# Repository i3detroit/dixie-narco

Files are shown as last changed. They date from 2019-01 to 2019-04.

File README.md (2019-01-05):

# dixie-narco
Replacement controller for a Dixie-Narco drink vending machine

Initial reverse-engineering and machine details located in the history of the [equipment page](https://www.i3detroit.org/wiki/Dixie_Narco_Soda_Machine), which will be a living document for the current status of the machine.

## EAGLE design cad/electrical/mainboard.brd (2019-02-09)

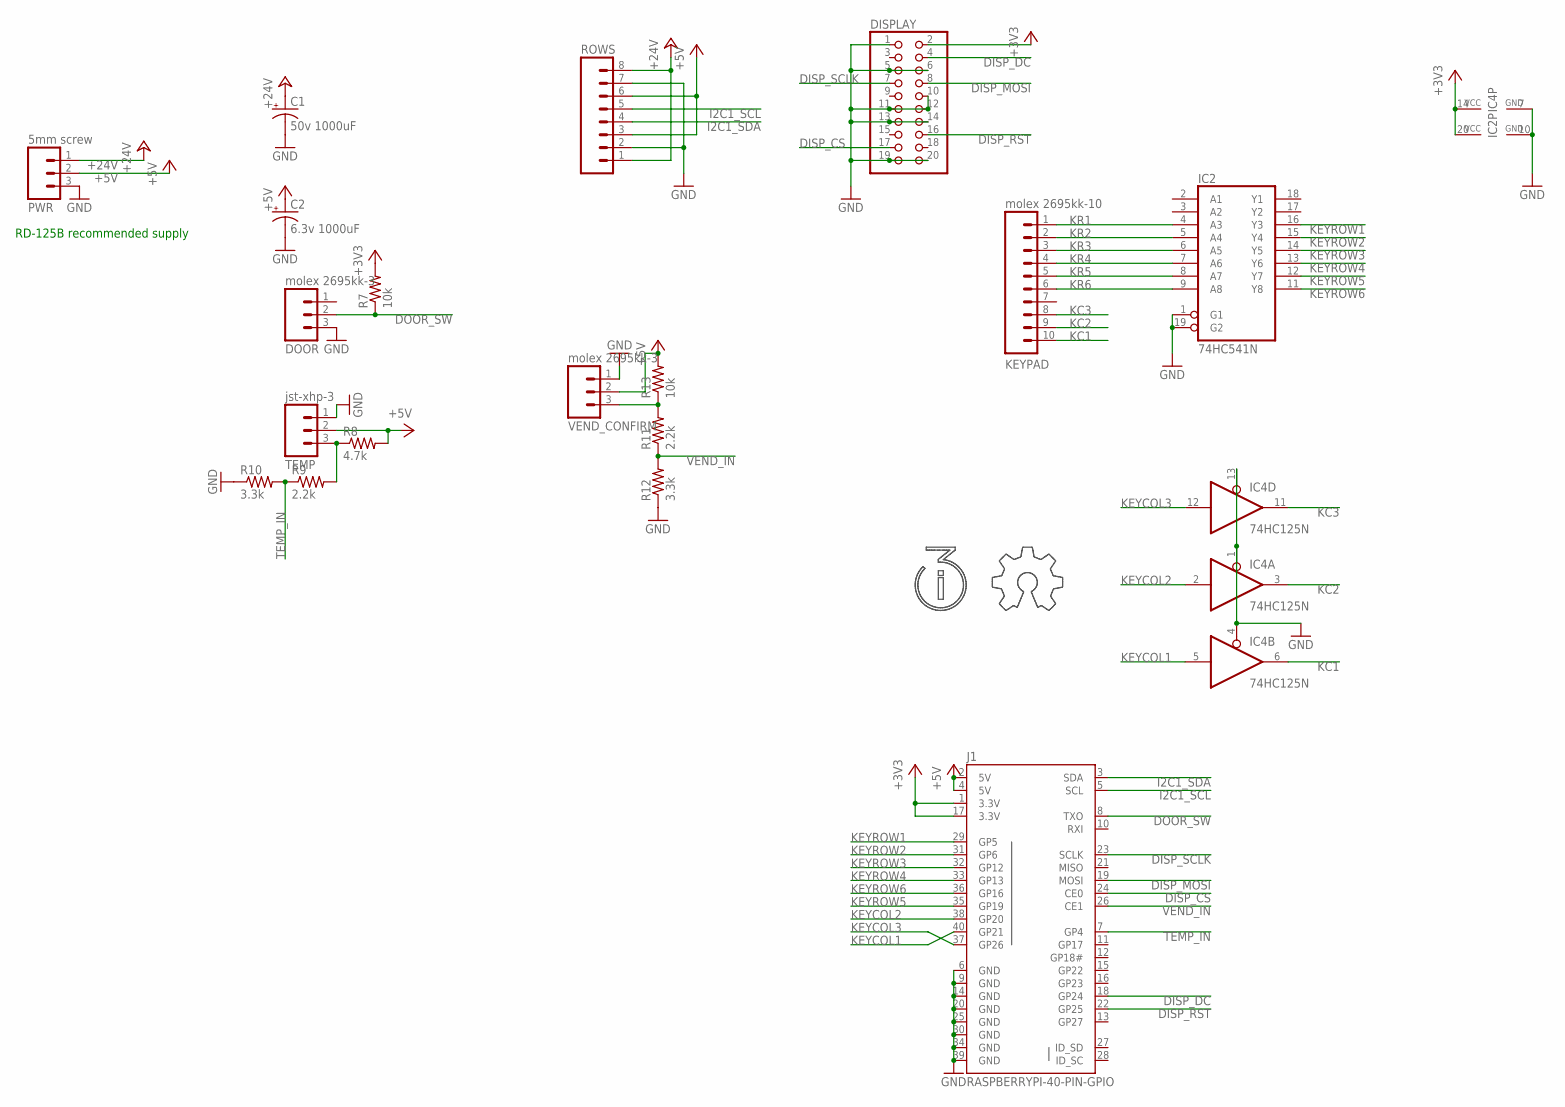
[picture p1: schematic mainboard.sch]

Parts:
C1: 50v 1000uF; CPOL-RADIAL-1000UF-25V
C2: 6.3v 1000uF; CPOL-RADIAL-1000UF-25V
DISPLAY: PINHD-2X10; 2X10
DOOR: molex 2695kk-3; MOLEX-1X3
IC2: 74HC541N; DIL20
IC4: 74HC125N; DIL14
J1: RASPBERRYPI-40-PIN-GPIO; 2X20-SHROUDED
KEYPAD: molex 2695kk-10; 1X10_LOCK
PWR: 5mm screw; SCREWTERMINAL-5MM-3
R7, R13: 10k; 1206
R8: 4.7k; 1206
R9, R11: 2.2k; 1206
R10, R12: 3.3k; 1206
ROWS: M08FEMALE_LOCK; 1X08_FEMALE_LOCK
TEMP: jst-xhp-3; 1X03
U$1: I3LOGO
U$2: OSHWLOGO
VEND_CONFIRM: molex 2695kk-3; MOLEX-1X3

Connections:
+3V3: DISPLAY.2, IC2.20 (VCC), IC4.14 (VCC), J1.1 (3.3V), J1.17 (3.3V), R7.2
+5V: C2.+, J1.2 (5V), J1.4 (5V), PWR.2, R8.2, R13.2, ROWS.3, ROWS.6, TEMP.2, VEND_CONFIRM.2
+24V: C1.+, PWR.1, ROWS.1, ROWS.8
DISP_CS: DISPLAY.17, J1.24 (CE0)
DISP_DC: DISPLAY.4, J1.18 (GP24)
DISP_MOSI: DISPLAY.8, J1.19 (MOSI)
DISP_RST: DISPLAY.16, J1.22 (GP25)
DISP_SCLK: DISPLAY.7, J1.23 (SCLK)
DOOR_SW: DOOR.2, J1.8 (TXO), R7.1
GND: C1.-, C2.-, DISPLAY.1, DISPLAY.5, DISPLAY.6, DISPLAY.10, DISPLAY.11, DISPLAY.12, DISPLAY.13, DISPLAY.14, DISPLAY.19, DISPLAY.20, DOOR.3, IC2.1 (G1), IC2.10 (GND), IC2.19 (G2), IC4.1 (OE), IC4.4 (OE), IC4.7 (GND), IC4.13 (OE), J1.6 (GND), J1.9 (GND), J1.14 (GND), J1.20 (GND), J1.25 (GND), J1.30 (GND), J1.34 (GND), J1.39 (GND), PWR.3, R10.1, R12.1, ROWS.2, ROWS.7, TEMP.1, VEND_CONFIRM.1
I2C1_SCL: J1.5 (SCL), ROWS.5
I2C1_SDA: J1.3 (SDA), ROWS.4
KC1: IC4.6 (O), KEYPAD.10
KC2: IC4.3 (O), KEYPAD.9
KC3: IC4.11 (O), KEYPAD.8
KEYCOL1: IC4.5 (I), J1.40 (GP21)
KEYCOL2: IC4.2 (I), J1.38 (GP20)
KEYCOL3: IC4.12 (I), J1.37 (GP26)
KEYROW1: IC2.16 (Y3), J1.29 (GP5)
KEYROW2: IC2.15 (Y4), J1.31 (GP6)
KEYROW3: IC2.14 (Y5), J1.32 (GP12)
KEYROW4: IC2.13 (Y6), J1.33 (GP13)
KEYROW5: IC2.12 (Y7), J1.35 (GP19)
KEYROW6: IC2.11 (Y8), J1.36 (GP16)
KR1: IC2.4 (A3), KEYPAD.1
KR2: IC2.5 (A4), KEYPAD.2
KR3: IC2.6 (A5), KEYPAD.3
KR4: IC2.7 (A6), KEYPAD.4
KR5: IC2.8 (A7), KEYPAD.5
KR6: IC2.9 (A8), KEYPAD.6
unnamed: R8.1, R9.2, TEMP.3
unnamed: R11.2, R13.1, VEND_CONFIRM.3
TEMP_IN: J1.7 (GP4), R9.1, R10.2
VEND_IN: J1.26 (CE1), R11.1, R12.2

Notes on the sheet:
RD-125B recommended supply

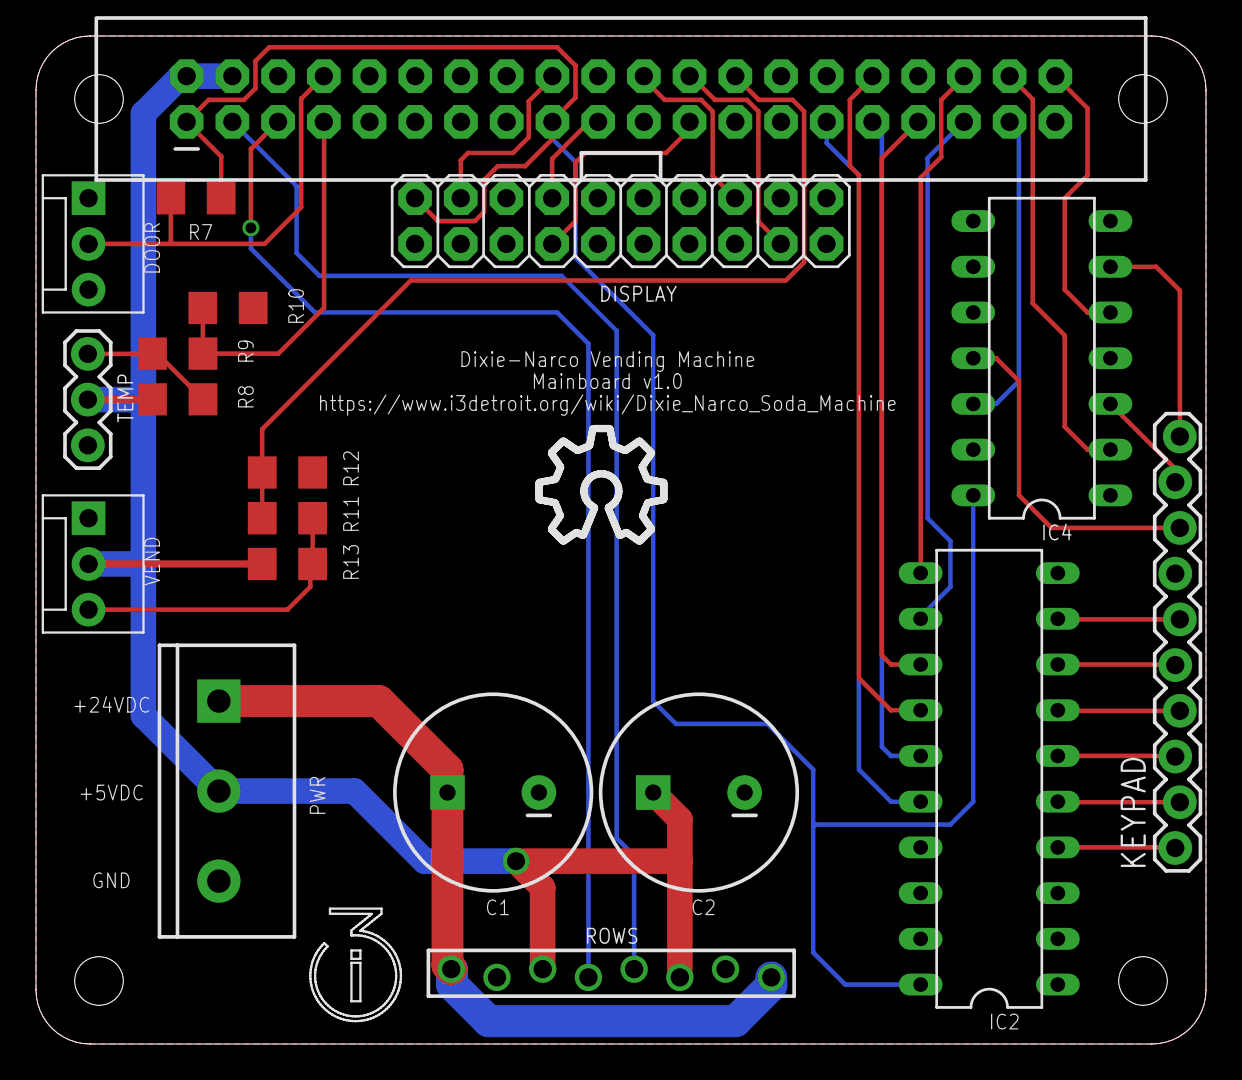
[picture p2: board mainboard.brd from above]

Board: 2 copper layers, 65.0 x 56.0 mm, 21 parts (0 on the bottom side), 34 nets.

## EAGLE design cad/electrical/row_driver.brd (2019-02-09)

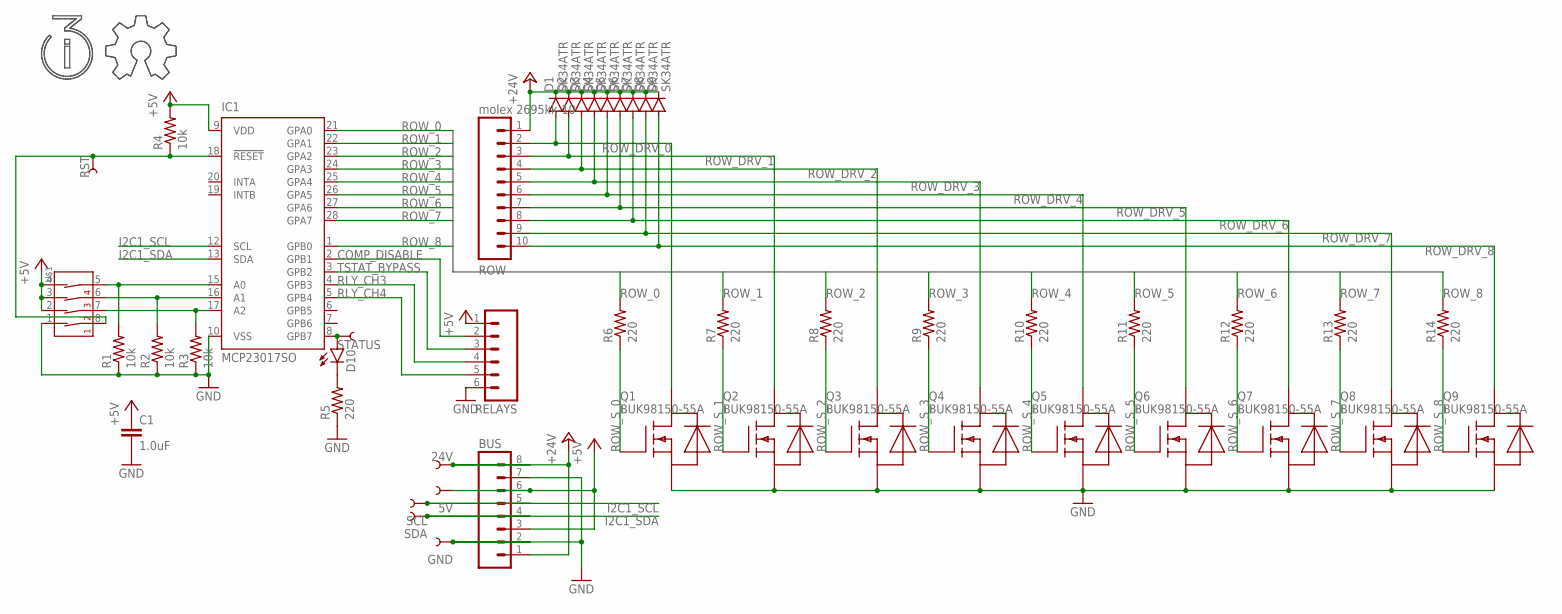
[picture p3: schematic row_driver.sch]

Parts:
5V, 24V: TEST-POINTTP_15TH_THRU; TP_15TH
BUS: M08FEMALE_LOCK; 1X08_FEMALE_LOCK
C1: 1.0uF; 0603-CAP
D1, D2, D3, D4, D5, D6, D7, D8, D9: SK34ATR; SMA-DIODE
D10: LED1206; LED-1206
GND: TEST-POINTTP_15TH_THRU; TP_15TH
IC1: MCP23017SO; SO28W
Q1, Q2, Q3, Q4, Q5, Q6, Q7, Q8, Q9: BUK98150-55A; SOT223
R1, R2, R3, R4: 10k; 0805
R5, R6, R7, R8, R9, R10, R11, R12, R13, R14: 220; 0805
RELAYS: M06LOCK; 1X06_LOCK
ROW: molex 2695kk-10; 1X10_LOCK
RST: TEST-POINTTP_15TH_THRU; TP_15TH
SCL: TEST-POINTTP_15TH_THRU; TP_15TH
SDA: TEST-POINTTP_15TH_THRU; TP_15TH
STATUS: TEST-POINTTP_15TH_THRU; TP_15TH
U$1: 4-POS-DIP; 4-POS-DIP-SMD
U$2: I3LOGO
U$4: OSHWLOGO

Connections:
+5V: 5V.P$1, BUS.3, BUS.6, C1.1, IC1.9 (VDD), R4.2, RELAYS.1, U$1.2 (2A), U$1.3 (3A), U$1.4 (4A)
+24V: 24V.P$1, BUS.1, BUS.8, D1.C, D2.C, D3.C, D4.C, D5.C, D6.C, D7.C, D8.C, D9.C, ROW.1
A0: IC1.15 (A0), R1.2, U$1.5 (4B)
A1: IC1.16 (A1), R2.2, U$1.6 (3B)
A2: IC1.17 (A2), R3.2, U$1.7 (2B)
COMP_DISABLE: IC1.2 (GPB1), RELAYS.2
GND: BUS.2, BUS.7, C1.2, GND.P$1, IC1.10 (VSS), Q1.3 (S), Q2.3 (S), Q3.3 (S), Q4.3 (S), Q5.3 (S), Q6.3 (S), Q7.3 (S), Q8.3 (S), Q9.3 (S), R1.1, R2.1, R3.1, R5.1, RELAYS.6, U$1.1 (1A)
I2C1_SCL: BUS.5, IC1.12 (SCL), SCL.P$1
I2C1_SDA: BUS.4, IC1.13 (SDA), SDA.P$1
unnamed: D10.C, R5.2
RLY_CH3: IC1.4 (GPB3), RELAYS.4
RLY_CH4: IC1.5 (GPB4), RELAYS.5
ROW_0: IC1.21 (GPA0), R6.2
ROW_1: IC1.22 (GPA1), R7.2
ROW_2: IC1.23 (GPA2), R8.2
ROW_3: IC1.24 (GPA3), R9.2
ROW_4: IC1.25 (GPA4), R10.2
ROW_5: IC1.26 (GPA5), R11.2
ROW_6: IC1.27 (GPA6), R12.2
ROW_7: IC1.28 (GPA7), R13.2
ROW_8: IC1.1 (GPB0), R14.2
ROW_DRV_0: D1.A, Q1.2 (D), Q1.4 (D), ROW.2
ROW_DRV_1: D2.A, Q2.2 (D), Q2.4 (D), ROW.3
ROW_DRV_2: D3.A, Q3.2 (D), Q3.4 (D), ROW.4
ROW_DRV_3: D4.A, Q4.2 (D), Q4.4 (D), ROW.5
ROW_DRV_4: D5.A, Q5.2 (D), Q5.4 (D), ROW.6
ROW_DRV_5: D6.A, Q6.2 (D), Q6.4 (D), ROW.7
ROW_DRV_6: D7.A, Q7.2 (D), Q7.4 (D), ROW.8
ROW_DRV_7: D8.A, Q8.2 (D), Q8.4 (D), ROW.9
ROW_DRV_8: D9.A, Q9.2 (D), Q9.4 (D), ROW.10
ROW_S_0: Q1.1 (G), R6.1
ROW_S_1: Q2.1 (G), R7.1
ROW_S_2: Q3.1 (G), R8.1
ROW_S_3: Q4.1 (G), R9.1
ROW_S_4: Q5.1 (G), R10.1
ROW_S_5: Q6.1 (G), R11.1
ROW_S_6: Q7.1 (G), R12.1
ROW_S_7: Q8.1 (G), R13.1
ROW_S_8: Q9.1 (G), R14.1
RST: IC1.18 (!RESET), R4.1, RST.P$1, U$1.8 (1B)
STATUS: D10.A, IC1.8 (GPB7), STATUS.P$1
TSTAT_BYPASS: IC1.3 (GPB2), RELAYS.3

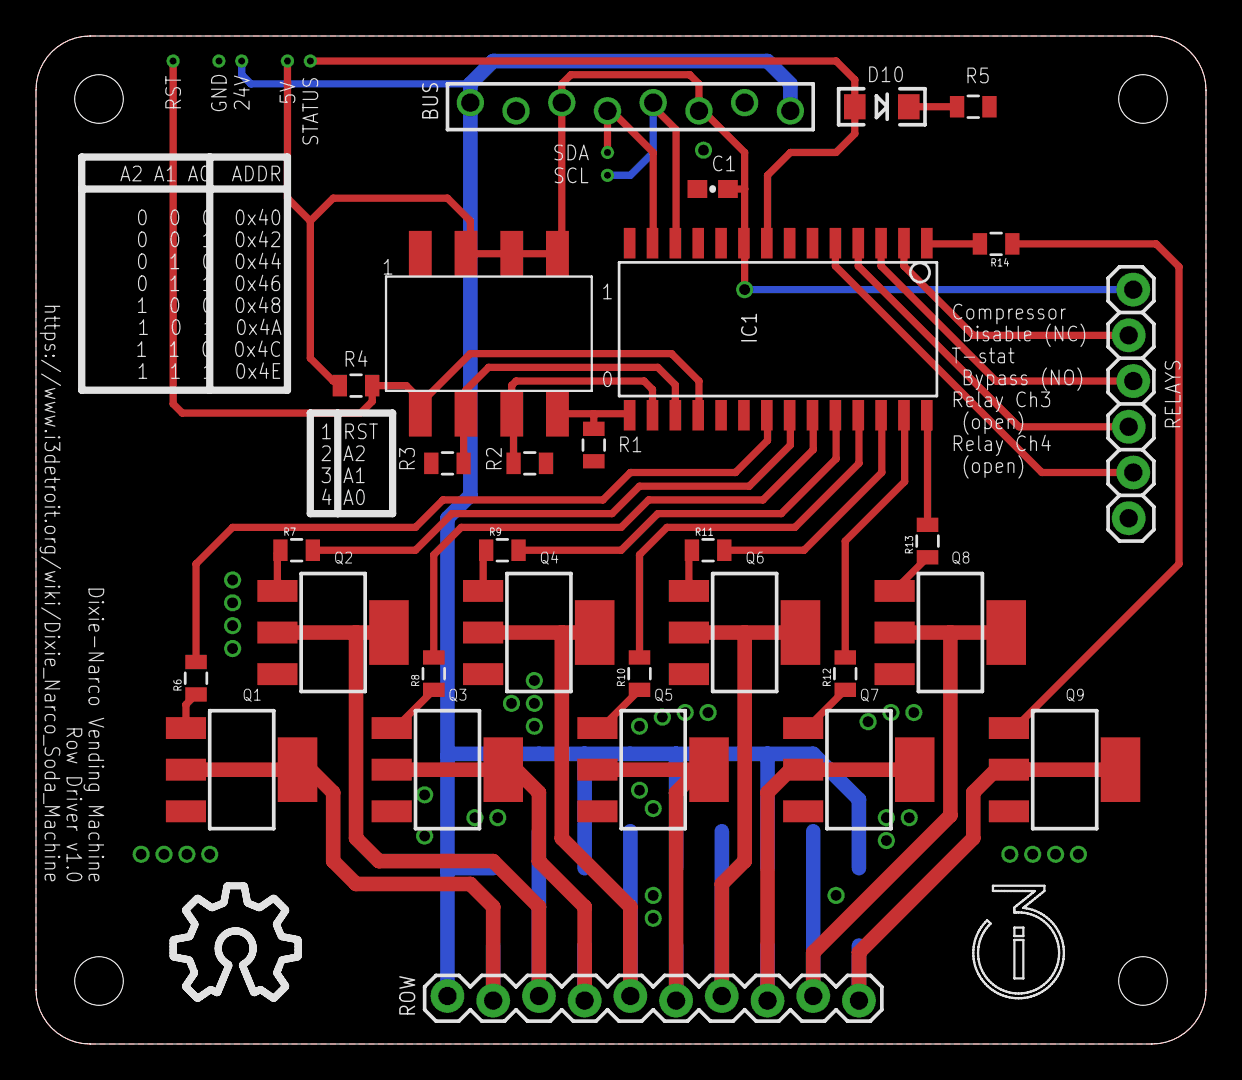
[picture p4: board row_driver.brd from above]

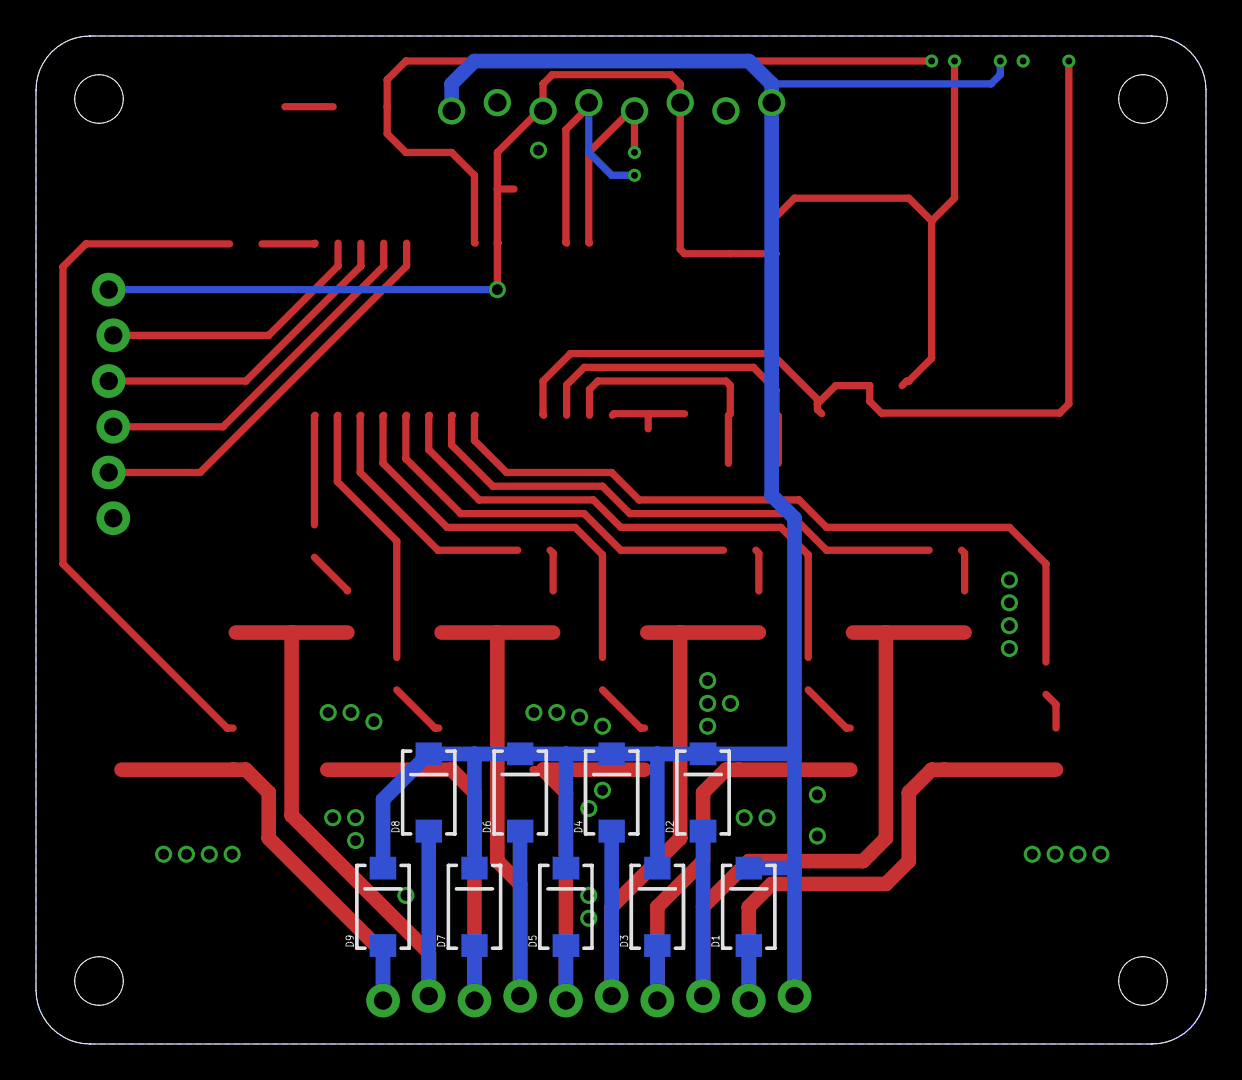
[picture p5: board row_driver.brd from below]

Board: 2 copper layers, 65.0 x 56.0 mm, 48 parts (9 on the bottom side), 42 nets.

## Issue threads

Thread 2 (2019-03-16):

Polyfuses are useful

agmlego, 2019-03-16:
Adding polyfuses on the board would be usefult to stop smoking FETs when channels get stuck on in software. 2.5A/50V polyfuse seems to work OK in practice.

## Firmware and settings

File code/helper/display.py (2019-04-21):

#!/usr/bin/env python3
from luma.core.interface.serial import spi
from luma.core.render import canvas
from luma.oled.device import ssd1322

from PIL import Image,ImageFont

import signal

class Display:
    def __init__(self):
        self._serial = spi(device=0, port=0, bus_speed_hz=32000000)
        self._device = ssd1322(self._serial,width=256,height=64)
        self._fnt = ImageFont.truetype('/home/agmlego/src/b612/fonts/ttf/B612Mono-Regular.ttf',16)
        signal.signal(signal.SIGALRM,self.handler)

    def handler(self,signum, frame):
        print('Time!')
        with canvas(self._device) as draw:
            draw.rectangle(self._device.bounding_box, outline='black', fill='black')

    def splash(self,slot=''):
        signal.alarm(60)
        with canvas(self._device) as draw:
            draw.rectangle(self._device.bounding_box, outline='white', fill='black')
            draw.text((2,2),'Welcome to i3Detroit!\nPlease make a selection: \n%s'%slot,font=self._fnt,fill='white')
    
    def draw_row(self,row):
        self.splash(row)
    
    def draw_slot(self,row,slot):
        self.splash(row+slot)

if __name__ == '__main__':
    from time import sleep
    disp = Display()
    while True:
        disp.splash()
        row = input('Row? ')
        disp.draw_row(row)
        slot = input('Slot? ')
        disp.draw_slot(row,slot)
        sleep(1)

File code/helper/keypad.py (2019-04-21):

#!/usr/bin/env python3
from time import sleep
import pigpio

class Keypad:
    _cols = [21, 20, 26]
    _rows = [5, 6, 12, 13, 19, 16]

    _keys = [
            ['F','*','CLR'],
            ['E','9','0'],
            ['D','7','8'],
            ['C','5','6'],
            ['B','3','4'],
            ['A','1','2']
        ]
    def __init__(self):
        self._pi = pigpio.pi()

        for col in self._cols:
            self._pi.set_mode(col,pigpio.OUTPUT)
            self._pi.write(col,0)

        for row in self._rows:
            self._pi.set_mode(row,pigpio.INPUT)
            self._pi.set_pull_up_down(row,pigpio.PUD_DOWN)

    def scan(self,blocking=True):
        char = None
        while char is None:
            for col in self._cols:
                self._pi.write(col,1)
                for row in self._rows:
                    state = self._pi.read(row)
                    if state:
                        sleep(0.05)
                        state = self._pi.read(row)
                        if state:
                            char = self._keys[self._rows.index(row)][self._cols.index(col)]
                            #print('(%d,%d): %s'%(row,col,char))
                self._pi.write(col,0)
                sleep(0.05)
            if not blocking:
                break
        return char

    def __del__(self):
        self._pi.stop()

if __name__ == '__main__':
    k = Keypad()
    while True:
        print(k.scan())

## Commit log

2018-12-31 Row driver schematic and board complete, ready for testing.
    [row_driver.brd, row_driver.sch]
2019-01-05 Initial draft of mainboard.
    [mainboard.brd, mainboard.sch]
2019-01-05 Added relay header for the ubiquitous 4-channel relay boards. Two are immediately assigned: one acts in NC in series with the compressor (so the controller can interrupt compressor power on demand, b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
    [row_driver.brd, row_driver.sch]
2019-02-09 Completed mainboard design edits; buffers for keypad, reworked 5V feed.
    [mainboard.brd, mainboard.sch]
2019-02-09 Added GND vias on row_driver.
    [row_driver.brd]
2019-02-09 No the one-wire sensor does not need a $0.252 resistor as a pull-up the $0.0254 ones are fine kthxbai.
    [mainboard.brd, mainboard.sch]
2019-03-16 Organizantional cleanup
    [mainboard.brd, mainboard.sch, row_driver.brd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]
2019-03-16 Row driver test helper script
2019-03-23 Added adapter plate for OLED screen to machine service door posts.
2019-03-27 Added pin mapping file maybe this is even readable by machine.
2019-04-20 Remapped slot labels
2019-04-21 rename row driver
2019-04-21 modularized row driver
2019-04-21 tweaks to fix default display
    [display.py]
2019-04-21 shortened debounce period for cleaner presses
    [keypad.py]
2019-04-21 Timer for screen blanking to save OLED

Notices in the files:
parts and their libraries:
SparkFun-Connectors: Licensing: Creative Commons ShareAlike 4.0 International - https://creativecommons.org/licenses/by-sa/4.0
